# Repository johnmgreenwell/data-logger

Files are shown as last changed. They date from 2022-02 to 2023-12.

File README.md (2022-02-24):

# Data Logger PCB Project

Custom PCB for Battery-Powered SD Card Data Logging

## Overview

This custom PCB incorporates an [Atmega328 microcontroller](https://www.digikey.com/en/products/detail/microchip-technology/ATMEGA328P-AU/1832260) interfaced with a [DS1037 RTC](https://www.digikey.com/en/products/detail/analog-devices-inc-maxim-integrated/DS1307Z/11523034) for time-keeping and a [MicroSD card slot](https://www.mouser.com/ProductDetail/Wurth-Elektronik/693072010801?qs=7gQLVZk5cPmw4uU1mAcUFg%3D%3D) for nonvolatile data write/read. The board may be powered with 3.3V externally or with a Li-Po battery able to be recharged on the board using adjacent 5V-GND pins and monitored by a [TP4054 linear charger IC](https://www.utsource.net/itm/p/5323872.html?digipart=1).

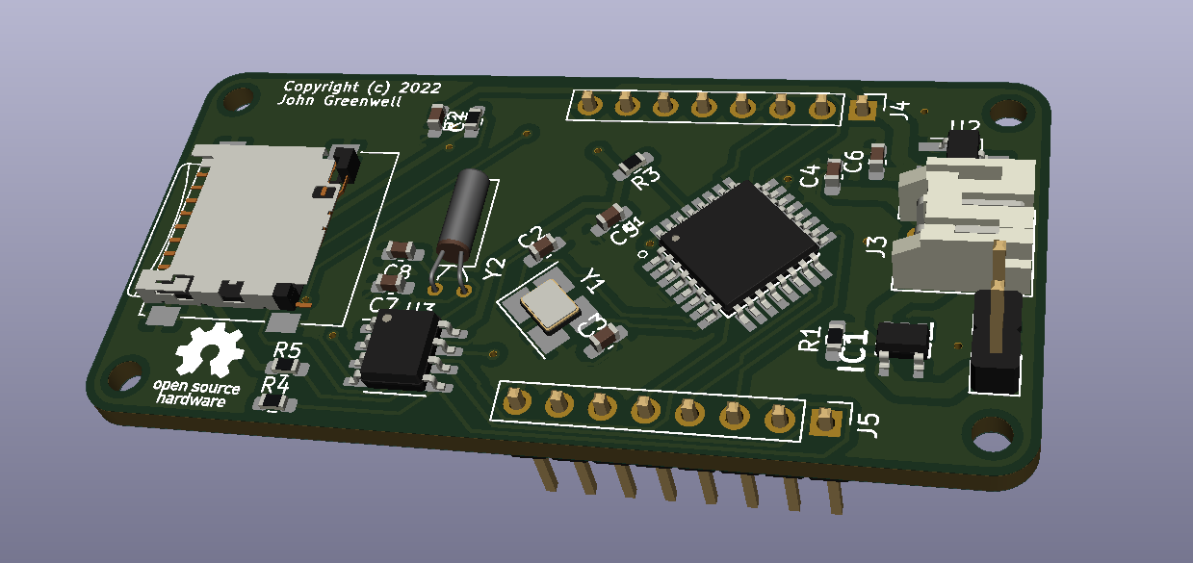
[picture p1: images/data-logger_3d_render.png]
Board 3D Render


Pin header placement is designed to be breadboard-friendly. No components are soldered to the bottom of the board for space and simplicity consideration, as well as for opportunity to attach a coincell battery on the underside of the board for the RTC if desired. The board is designed in KiCad 5 with all source files available in the project [CAD directory](/cad).

## Usage

Interface with the SD card is accomplished by with the hardware SPI pins on the microcontroller, and similarly interface with the RTC is done with the hardware I2C pins. The SQW/OUT pin from the RTC is hard-wired to the INT0 pin on the microcontroller as input, allowing for events triggered on impulse from RTC signals, including wakeup from sleep modes for power-saving. Likewise, the VBAT pin on the RTC is available on an external pin so that a coincell battery may be attached to prevent time erasure on detachment of Li-Po or external battery.

Any suitable SPI SD library or I2C DS1307 RTC library may be used in the code for the microcontroller, provided the appropriate hardware protocols are utilized, as in the example code below.

```cpp
#include <TimeLib.h>
#include <DS1307RTC.h>
#include <SD.h>
...
tmElements_t tm;
File root;
...
const uint8_t INT0_PIN = 2;
const uint8_t CS_PIN = 10;
...
void setup(void) {
    bool parse=false;
    bool config=false;

    pinMode(INT0_PIN, INPUT);
    SPI.begin();
    Wire.begin();

    // Initialize RTC ref. DS1307RTC lib by Paul Stoffregen
    if (getDate(__DATE__) && getTime(__TIME__)) {
        parse = true;
        if (RTC.write(tm)) {
            config = true;
        }
  }

    // Initialize SD
    if (!SD.begin(CS_PIN)) {
        while (1);
    }
    root = SD.open("/");

}
...
```

## Schematic

The overall schematic for the test setup, along with its associated CAD files are included as composed in KiCad 5.

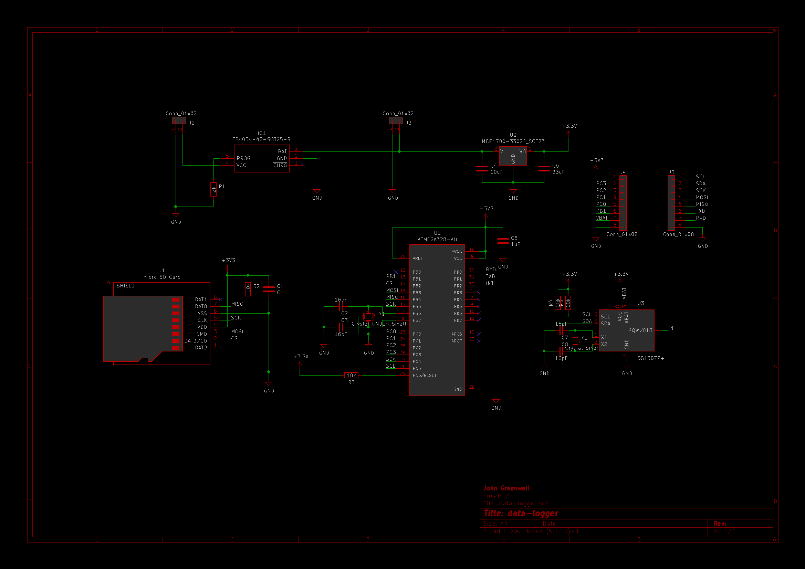
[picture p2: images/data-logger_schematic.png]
Board Schematic


Improvements to this design could include silkscreen labels of pins for convenience, and possibly a re-orientation or expansion to the pin headers. Rather than VBAT as an external pin, footprint for a coincell battery holder might be added to the bottom of the board as optional. Additionally, the CHRG pin on the battery IC might be attached to an LED or tied back to the microcontroller for monitoring.

## License

MIT © 2022 John Greenwell

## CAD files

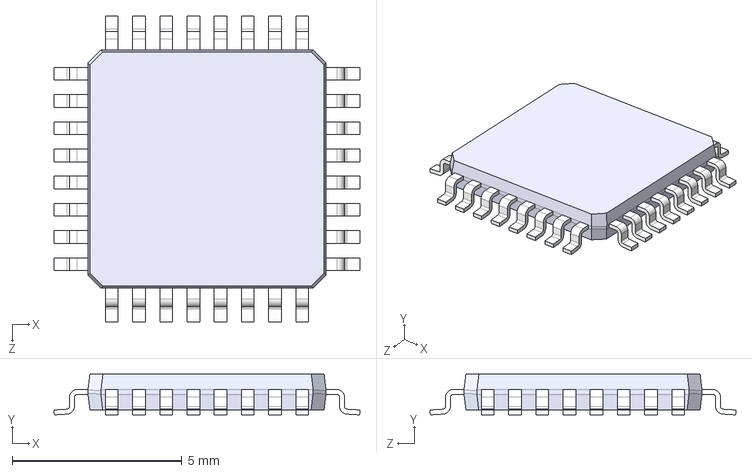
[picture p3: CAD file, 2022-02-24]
cad/Components/ATMEGA328-AU.step
9.00 x 1.20 x 9.00 mm

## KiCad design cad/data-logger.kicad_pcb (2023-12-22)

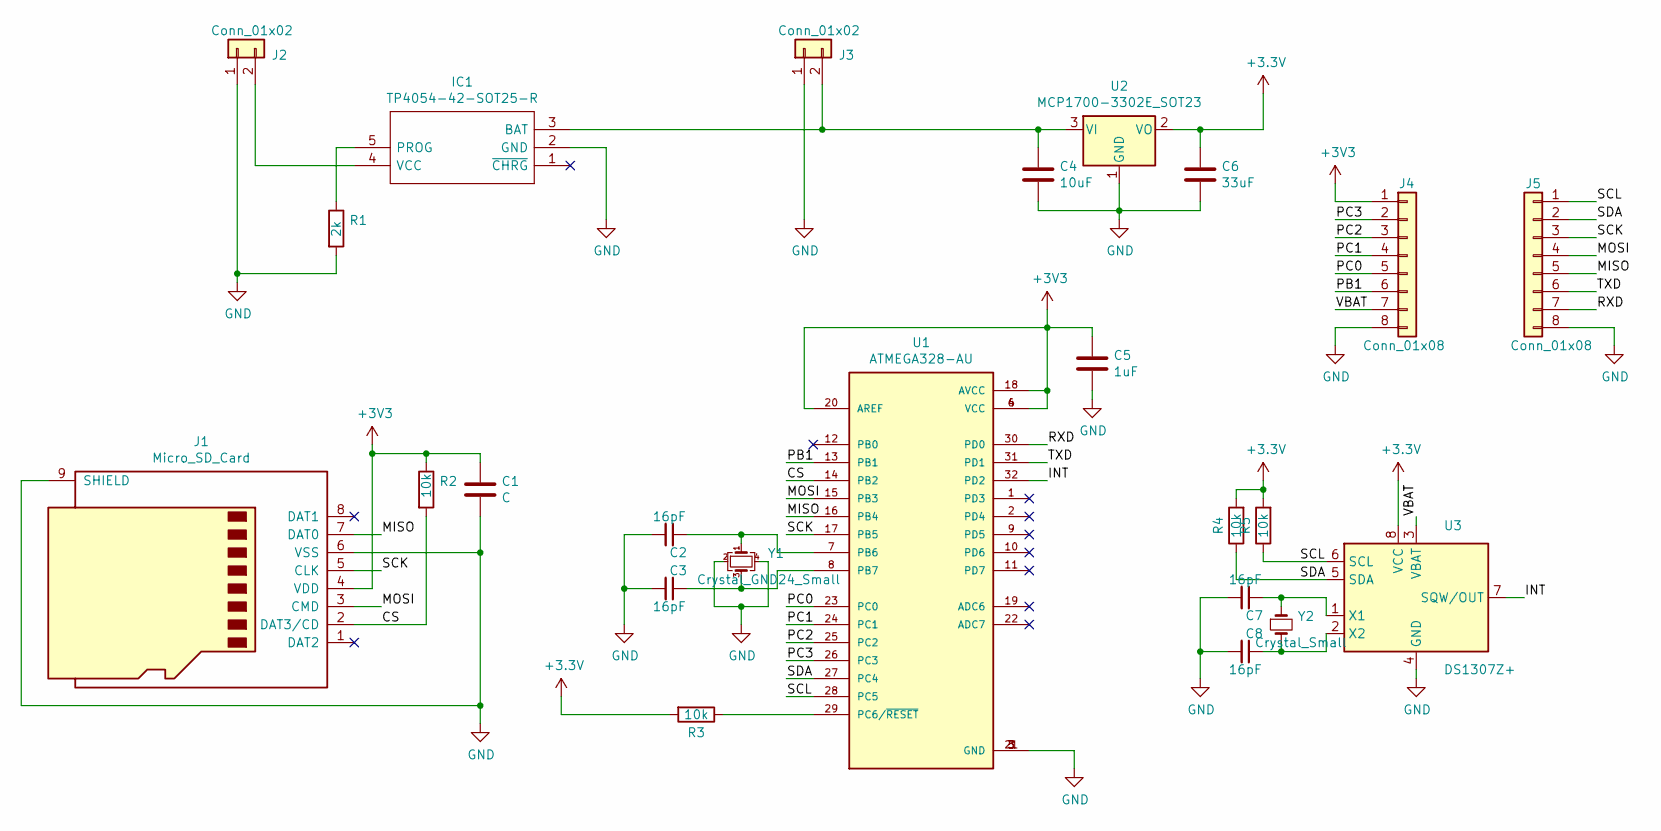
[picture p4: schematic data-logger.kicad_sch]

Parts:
C1: C; C_0603_1608Metric_Pad1.08x0.95mm_HandSolder
C2, C3, C7, C8: 16pF; C_0603_1608Metric_Pad1.08x0.95mm_HandSolder
C4: 10uF; C_0603_1608Metric_Pad1.08x0.95mm_HandSolder
C5: 1uF; C_0603_1608Metric_Pad1.08x0.95mm_HandSolder
C6: 33uF; C_0603_1608Metric_Pad1.08x0.95mm_HandSolder
IC1: TP4054-42-SOT25-R; SOT95P280X100-5N; Manufacturer_Part_Number TP4054-42-SOT25-R
J1: Micro_SD_Card; microSD_HC_Wuerth_693072010801
J2: Conn_01x02; PinHeader_1x02_P2.54mm_Vertical
J3: Conn_01x02; JST_PH_S2B-PH-K_1x02_P2.00mm_Horizontal
J4, J5: Conn_01x08; PinHeader_1x08_P2.54mm_Vertical
R1: 2k; R_0603_1608Metric_Pad0.98x0.95mm_HandSolder
R2, R3, R4, R5: 10k; R_0603_1608Metric_Pad0.98x0.95mm_HandSolder
U1: ATMEGA328-AU; QFP80P900X900X120-32N
U2: MCP1700-3302E_SOT23; SOT-23W_Handsoldering
U3: DS1307Z+; SOIC-8_3.9x4.9mm_P1.27mm
Y1: Crystal_GND24_Small; Crystal_SMD_TXC_7M-4Pin_3.2x2.5mm_HandSoldering
Y2: Crystal_Small; Crystal_C26-LF_D2.1mm_L6.5mm_Horizontal

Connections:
/CS: J1.2 (DAT3/CD), R2.2, U1.14 (PB2)
/INT: U1.32 (PD2), U3.7 (SQW/OUT)
/MISO: J1.7 (DAT0), J5.5, U1.16 (PB4)
/MOSI: J1.3 (CMD), J5.4, U1.15 (PB3)
/PB1: J4.6, U1.13 (PB1)
/PC0: J4.5, U1.23 (PC0)
/PC1: J4.4, U1.24 (PC1)
/PC2: J4.3, U1.25 (PC2)
/PC3: J4.2, U1.26 (PC3)
/RXD: J5.7, U1.30 (PD0)
/SCK: J1.5 (CLK), J5.3, U1.17 (PB5)
/SCL: J5.1, R5.1, U1.28 (PC5), U3.6 (SCL)
/SDA: J5.2, R4.1, U1.27 (PC4), U3.5 (SDA)
/TXD: J5.6, U1.31 (PD1)
/VBAT: J4.7, U3.3 (VBAT)
GND: C1.2, C2.2, C3.2, C4.2, C5.2, C6.2, C7.2, C8.2, IC1.2 (GND), J1.6 (VSS), J1.9 (SHIELD), J2.1, J3.1, J4.8, J5.8, R1.2, U1.3 (GND), U1.5 (GND), U1.21 (GND), U2.1 (GND), U3.4 (GND), Y1.2, Y1.4
unnamed: C2.1, U1.7 (PB6), Y1.1
unnamed: C3.1, U1.8 (PB7), Y1.3
unnamed: C4.1, IC1.3 (BAT), J3.2, U2.3 (VI)
unnamed: C7.1, U3.1 (X1), Y2.1
unnamed: C8.1, U3.2 (X2), Y2.2
unnamed: IC1.4 (VCC), J2.2
unnamed: IC1.5 (PROG), R1.1
unnamed: R3.1, U1.29 (PC6/~RESET)

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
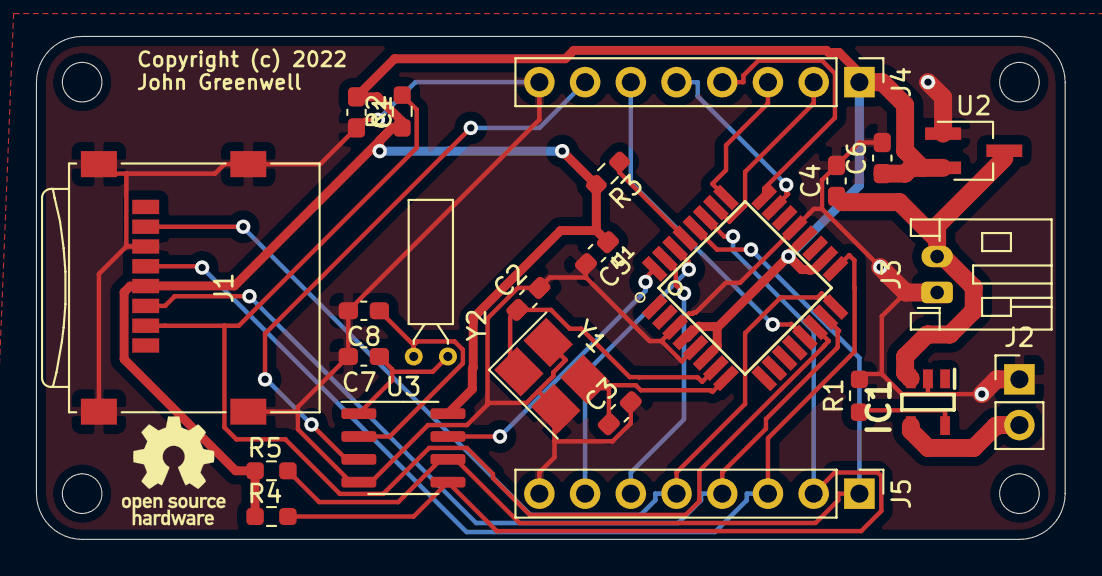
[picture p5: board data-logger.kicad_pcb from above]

Board: 2 copper layers, 57.2 x 27.9 mm, 28 parts (0 on the bottom side), 25 nets.

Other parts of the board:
MH1, MH2, MH3, MH4: MountingHole_2.2mm_M2

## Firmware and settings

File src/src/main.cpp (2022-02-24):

//----------------------------------------------------------------------------
// Name        : main.cpp
// Purpose     : Data Logger Test
// Description : 
//               This program intended to test the circuit for custom sd card
//               and RTC data-logger board.
//
// Platform    : Atmega328
// Language    : C++
// Framework   : Arduino
// Copyright   : MIT License 2022, John Greenwell
// Requires    : External Libraries : TimeLib.h
//                                    DS1307RTC.h
//                                    SD.h
//               Custom Libraries   : N/A
//----------------------------------------------------------------------------

#include <Arduino.h>
#include <Wire.h>
#include <SPI.h>
#include <TimeLib.h>
#include <DS1307RTC.h>
#include <SD.h>

// Objects
tmElements_t tm;
File root;

// Constants
const uint8_t INT0_PIN = 2;
const uint8_t CS_PIN = 10;
const char *monthName[12] = {
  "Jan", "Feb", "Mar", "Apr", "May", "Jun",
  "Jul", "Aug", "Sep", "Oct", "Nov", "Dec"
};

// Local Functions
bool getTime(const char *str);
bool getDate(const char *str);

// Main Program
void setup(void) {
    bool parse=false;
    bool config=false;

    pinMode(INT0_PIN, INPUT);
    SPI.begin();
    Wire.begin();

    // Initialize RTC ref. DS1307RTC lib by Paul Stoffregen
    if (getDate(__DATE__) && getTime(__TIME__)) {
        parse = true;
        if (RTC.write(tm)) {
            config = true;
        }
  }

    // Initialize SD
    if (!SD.begin(CS_PIN)) {
        while (1);
    }
    root = SD.open("/");

}

void loop() {
    delay(1000);
}

// ref. DS1307RTC library by Paul Stoffregen
bool getTime(const char *str) {
  int Hour, Min, Sec;

  if (sscanf(str, "%d:%d:%d", &Hour, &Min, &Sec) != 3) return false;
  tm.Hour = Hour;
  tm.Minute = Min;
  tm.Second = Sec;
  return true;
}

// ref. DS1307RTC library by Paul Stoffregen
bool getDate(const char *str) {
  char Month[12];
  int Day, Year;
  uint8_t monthIndex;

  if (sscanf(str, "%s %d %d", Month, &Day, &Year) != 3) return false;
  for (monthIndex = 0; monthIndex < 12; monthIndex++) {
    if (strcmp(Month, monthName[monthIndex]) == 0) break;
  }
  if (monthIndex >= 12) return false;
  tm.Day = Day;
  tm.Month = monthIndex + 1;
  tm.Year = CalendarYrToTm(Year);
  return true;
}

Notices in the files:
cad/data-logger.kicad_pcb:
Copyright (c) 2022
